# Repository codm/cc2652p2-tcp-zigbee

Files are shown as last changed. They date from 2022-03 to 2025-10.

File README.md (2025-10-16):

# cod.m ZigBee CC2652P2 TCP Coordinator
Initiated by Matthias' video to build a [ZigBee Coordinator with Ethernet connectivity](https://www.youtube.com/watch?v=Uz26JzOJVTc) we developed a small PCB to integrate everything in a small form factor - ready to go if you like.

The coordinator uses an CC2652P2 together with an [USR-K6](https://www.pusr.com/products/low-cost-ttl-to-ethernet-modules-usr-k6.html) serial ethernet gateway. The CC2652P2 is the current ZigBee implementation from Texas Intruments and supports ZigBee 3.x. The Z-Stack firmware is actively developed - much thanks to @koenkk again.

Should be usable with any Home Automation System that let's you use a TCP port instead of a local port. The module is tested with [io.broker](https://www.iobroker.net/) and [zigbee2mqtt](https://www.zigbee2mqtt.io/).

You can buy it at our webshop: https://shop.codm.de/automation/zigbee/40/zigbee-cc2652p2-tcp-ethernet-coordinator. It comes preconfigured with DHCP enabled, case and antenna.

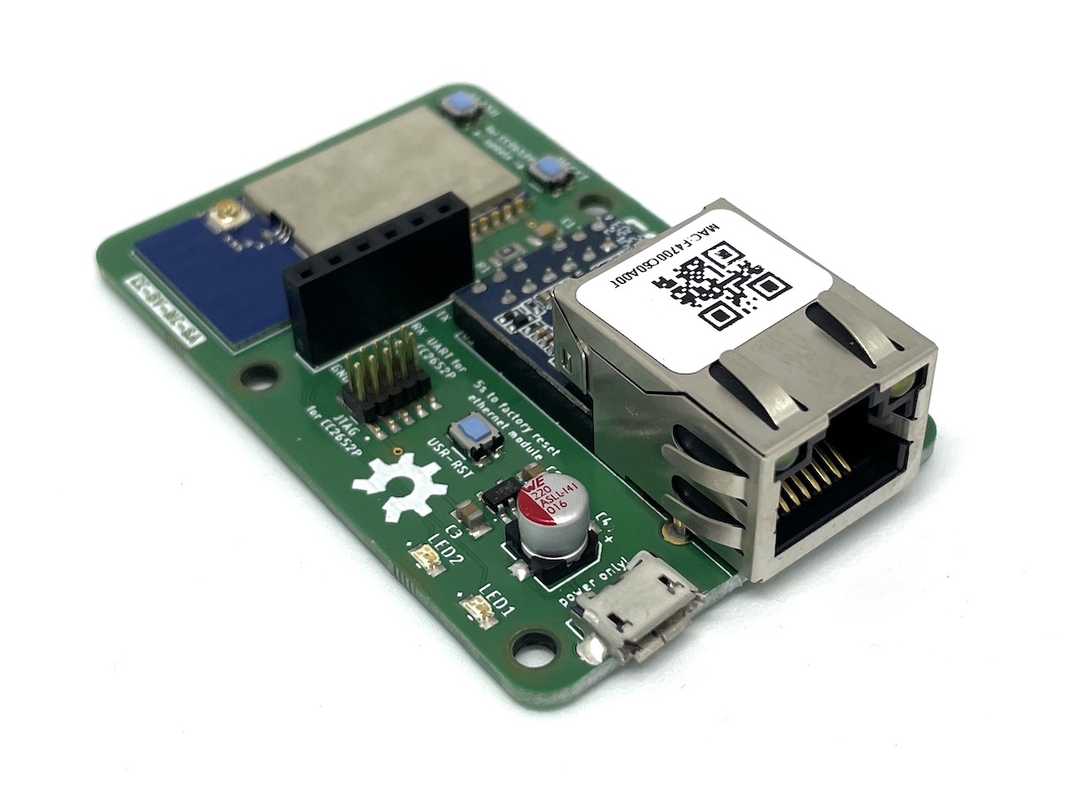
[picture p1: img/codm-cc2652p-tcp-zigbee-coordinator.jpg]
cod.m CC2652P2 TCP ZigBee Coordinator


To build a serial bridge the USR-K6 from USR IOT comes into play which implements everything needed to act as an TCP Server with a webinterface and in a small form factor.

You can find the files to 3d print the case on printables:
https://www.printables.com/de/model/179517-codm-cc2652p2-tcp-zigbee-coordiantor-case

## Configuration
If your home automation system let's you configure `TI ZStack/CCxxxx` devices as ZigBee coordinator over a TCP connection, you should be good to go. 

### io.broker
Install the zigbee adapter and configure the portname to `tcp://<ip-of-cc2652p-tcp>:20108` and choose `TI ZStack/CCxxxx` under type. After restarting the adapter everything should work. Check the logs for details like

```
Coordinator firmware version: {"type":"zStack3x0","meta":{"transportrev":2,"product":1,"majorrel":2,"mino rrel":7,"maintrel":1,"revision":20220103}}
```

### zigbee2mqtt
In `data/configuration.yaml` use the tcp connection under port in the section serial like so (including single quotes): 
```
serial: 
  port: 'tcp://<ip-of-cc2652p-tcp>:20108'
```

### USR-K6
If you factory reset the USR-K6 you'll need to configure the serial bridge again (see image). It act's as a TCP-Server on the given port.

The default IP of the USR-K6 is `192.168.0.7` and username/password for the webinterface is `admin/admin`.

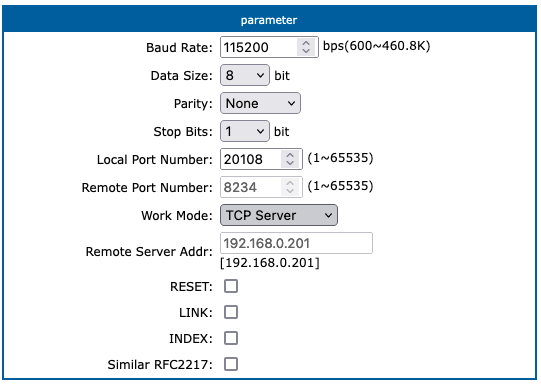
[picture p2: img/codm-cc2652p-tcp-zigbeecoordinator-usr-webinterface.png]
USR-K6 configuration


## Update
You can update the Z-Stack firmware on the CC2652P2 module via network using [ZigStar's stunning ZigStar MultiTool](https://zig-star.com/radio-docs/zigstar-multi-tool/).

Find the Z-Stack Firmware in [Koenkks Z-Stack Firmware Repository]([https://github.com/Koenkk/Z-Stack-firmware/tree/master/coordinator/Z-Stack_3.x.0/bin](https://github.com/Koenkk/Z-Stack-firmware/releases)) and check the table for which file use for the __cod.m ZigBee CC2652P2 TCP Coordinator__. Usually this is `CC1352P2_CC2652P_launchpad_*.zip`.

Open up the case and bring the CC2652P2 in bootloader mode by holding FLASH, pressing RESET and then release FLASH. After that choose the settings in the MultiTool according to the screenshot and of course use the IP of _your_ CC2652P TCP Coordinator:

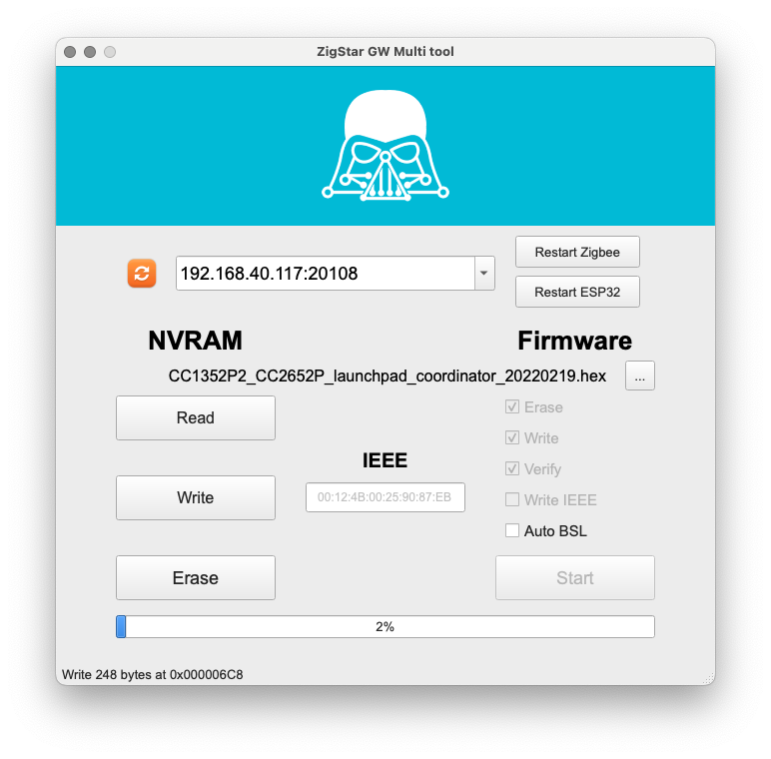
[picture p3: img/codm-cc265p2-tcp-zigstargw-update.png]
ZigStar MultTool Configuration for cod.m CC2652P2 ZigBee Coordinator


After that powercycle the module and use again.

Flashing via JTAG is also possible through the corresponding header.

# Thanks
* @klein0r Inital Idea - https://haus-automatisierung.com/
* @koenkk Z-Stack Firmware - https://github.com/Koenkk/Z-Stack-firmware
* @xyzroe ZigStar MultiTool - https://github.com/xyzroe/ZigStarGW-MT

# License
[CC-BY-NC-SA 4.0](https://creativecommons.org/licenses/by-nc-sa/4.0/)

[][cc-by-nc-sa]

[cc-by-nc-sa]: http://creativecommons.org/licenses/by-nc-sa/4.0/
[cc-by-nc-sa-image]: https://licensebuttons.net/l/by-nc-sa/4.0/88x31.png

cod.m GmbH, Patrik Mayer, 2022

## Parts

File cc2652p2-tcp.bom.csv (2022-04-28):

Qty | Value | Device | Package | Parts | Description | APPLICATION | CHIP-TECHNOLOGY | DATASHEET-URL | DESCRIPTION | DF | DIAMETER | DOMINANT-WAVELENGTH | EMITTING-COLOR | FORWARD-VOLTAGE | GENDER | GERDER | H | HEIGHT | I-LEAK | I-RIPPLE | INTERFACE-TYPE | IR | IR1 | L | LUMINOUS-INTENSITY | MANUFACTURER_NAME | MANUFACTURER_PART_NUMBER | MOUNT | MOUSER_PART_NUMBER | MOUSER_PRICE-STOCK | OPERATING-TEMPERATURE | OPERATION-FORCE | PACKAGING | PART-NUMBER | PEAK-WAVELENGTH | PINS | PITCH | POPULARITY | PROD_ID | QTY | ROWS | SPICEPREFIX | TECHNICAL-REFERENCE | TYPE | VALUE | VR | WORKING-VOLTAGE | Z
3 |  | 434153017835 | 434153017835 | FLASH, RESET, USR-RST | WS-TASV J-Bend SMT Tact Switch 3.5x2.9 mm |  |  | https://www.we-online.com/catalog/datasheet/434153017835.pdf |  |  |  |  |  |  |  |  | 1.7mm |  |  |  |  |  |  |  |  |  |  |  |  |  |  | 350g |  | 434153017835 |  |  |  |  |  | 4000
1 | 61300611821 | 6130XX11821_61300611821 | 61300611821 | J2 | WR-PHD 2.54 mm Socket Header |  |  | https://www.we-online.com/catalog/datasheet/61300611821.pdf |  |  |  |  |  |  | Socket Header |  |  |  |  |  |  | 3A |  |  |  |  |  | THT |  |  |  |  | Tray | 61300611821 |  | 6 | 2.54mm |  |  |  | Single |  |  | Straight | 61300611821
1 | 100n | C-EUC0805 | C0805 | C1 | CAPACITOR, European symbol |  |  |  |  |  |  |  |  |  |  |  |  |  |  |  |  |  |  |  |  |  |  |  |  |  |  |  |  |  |  |  |  | 88 |  |  |  | C
1 | 150080GS75000 | WL-SMCW_0805_150080GS75000 | WL-SMCW_0805 | LED1 | WL-SMCW SMT Mono-color Chip LED Waterclea |  | InGaN | https://www.we-online.com/catalog/datasheet/150080GS75000.pdf |  |  |  | 525nm | Green | 140° |  |  |  |  |  |  |  |  |  |  | 450mcd |  |  |  |  |  |  |  |  | 150080GS75000 | 515nm |  |  |  |  |  |  |  |  |  | 150080GS75000
1 | 150080RS75000 | WL-SMCW_0805_150080RS75000 | WL-SMCW_0805 | LED2 | WL-SMCW SMT Mono-color Chip LED Waterclea |  | AlInGaP | https://www.we-online.com/catalog/datasheet/150080RS75000.pdf |  |  |  | 625nm | Red | 140° |  |  |  |  |  |  |  |  |  |  | 150mcd |  |  |  |  |  |  |  |  | 150080RS75000 | 630nm |  |  |  |  |  |  |  |  |  | 150080RS75000
1 | 1k | R-EU_R0805 | R0805 | R1 | RESISTOR, European symbol |  |  |  |  |  |  |  |  |  |  |  |  |  |  |  |  |  |  |  |  |  |  |  |  |  |  |  |  |  |  |  |  | 86 |  |  |  | R
2 | 1u | C-EUC0805 | C0805 | C2, C3 | CAPACITOR, European symbol |  |  |  |  |  |  |  |  |  |  |  |  |  |  |  |  |  |  |  |  |  |  |  |  |  |  |  |  |  |  |  |  | 88 |  |  |  | C
1 | 20021121-00010C4LF | 20021121-00010C4LF | 2002112100010C4LF | JTAG | Headers & Wire Housings 1.27x1.27mm BTB, Hdr Unshrd, SMT, 10 Pos |  |  |  | Headers & Wire Housings 1.27x1.27mm BTB, Hdr Unshrd, SMT, 10 Pos |  |  |  |  |  |  |  |  | 4.55mm |  |  |  |  |  |  |  | Amphenol | 20021121-00010C4LF |  | 649-202112100010C4LF | https://www.mouser.com/Search/Refine.aspx?Keyword=649-202112100010C4LF
1 | 22 µF | WCAP-ASLL_5X5.5_865060342002 | WCAP-ASLL_5X5.5(DXL) | C4 | WCAP-ASLL Aluminium Electrolytic Capacitors |  |  | https://www.we-online.com/catalog/datasheet/865060342002.pdf |  | 16% | 5mm |  |  |  |  |  |  |  | 3.52uA | 150mA |  |  |  | 5.5mm |  |  |  |  |  |  | -55 °C up to +105 °C |  |  | 865060342002 |  |  |  |  |  |  |  |  | ASEC055220M016DVCTBB000 |  | 22 µF | 16V(DC) |  | 0.8Ohm
2 | 2k7 | R-EU_R0805 | R0805 | R2, R3 | RESISTOR, European symbol |  |  |  |  |  |  |  |  |  |  |  |  |  |  |  |  |  |  |  |  |  |  |  |  |  |  |  |  |  |  |  |  | 86 |  |  |  | R
1 | 629105150921 | 629105150921 | 629105150921 | J1 | WR-COM Micro USB 2.0 Type AB Horizontal | Micro USB 2.0 |  | https://www.we-online.com/catalog/datasheet/629105150921.pdf |  |  |  |  |  |  |  | Receptacle |  |  |  |  | Type AB |  | 1.8A |  |  |  |  | SMT |  |  |  |  | Tape and Reel | 629105150921 |  | 5 |  |  |  |  |  |  |  | Horizontal | 629105150921 |  | 30V(AC)
1 | AP2112K | V_REG_AP2112K-3.3V | SOT23-5 | U2 | AP2112 - 600mA CMOS LDO Regulator w/ Enable |  |  |  |  |  |  |  |  |  |  |  |  |  |  |  |  |  |  |  |  |  |  |  |  |  |  |  |  |  |  |  |  |  | VREG-12457 |  |  |  |  |  | 3.3V
1 | CC2652P2-DUOWEISI | CC2652P2-DUOWEISI | CC2652P2-DUOWEISI | U1
1 | USR-K6 | USR-K6 | USR-K6 | U3

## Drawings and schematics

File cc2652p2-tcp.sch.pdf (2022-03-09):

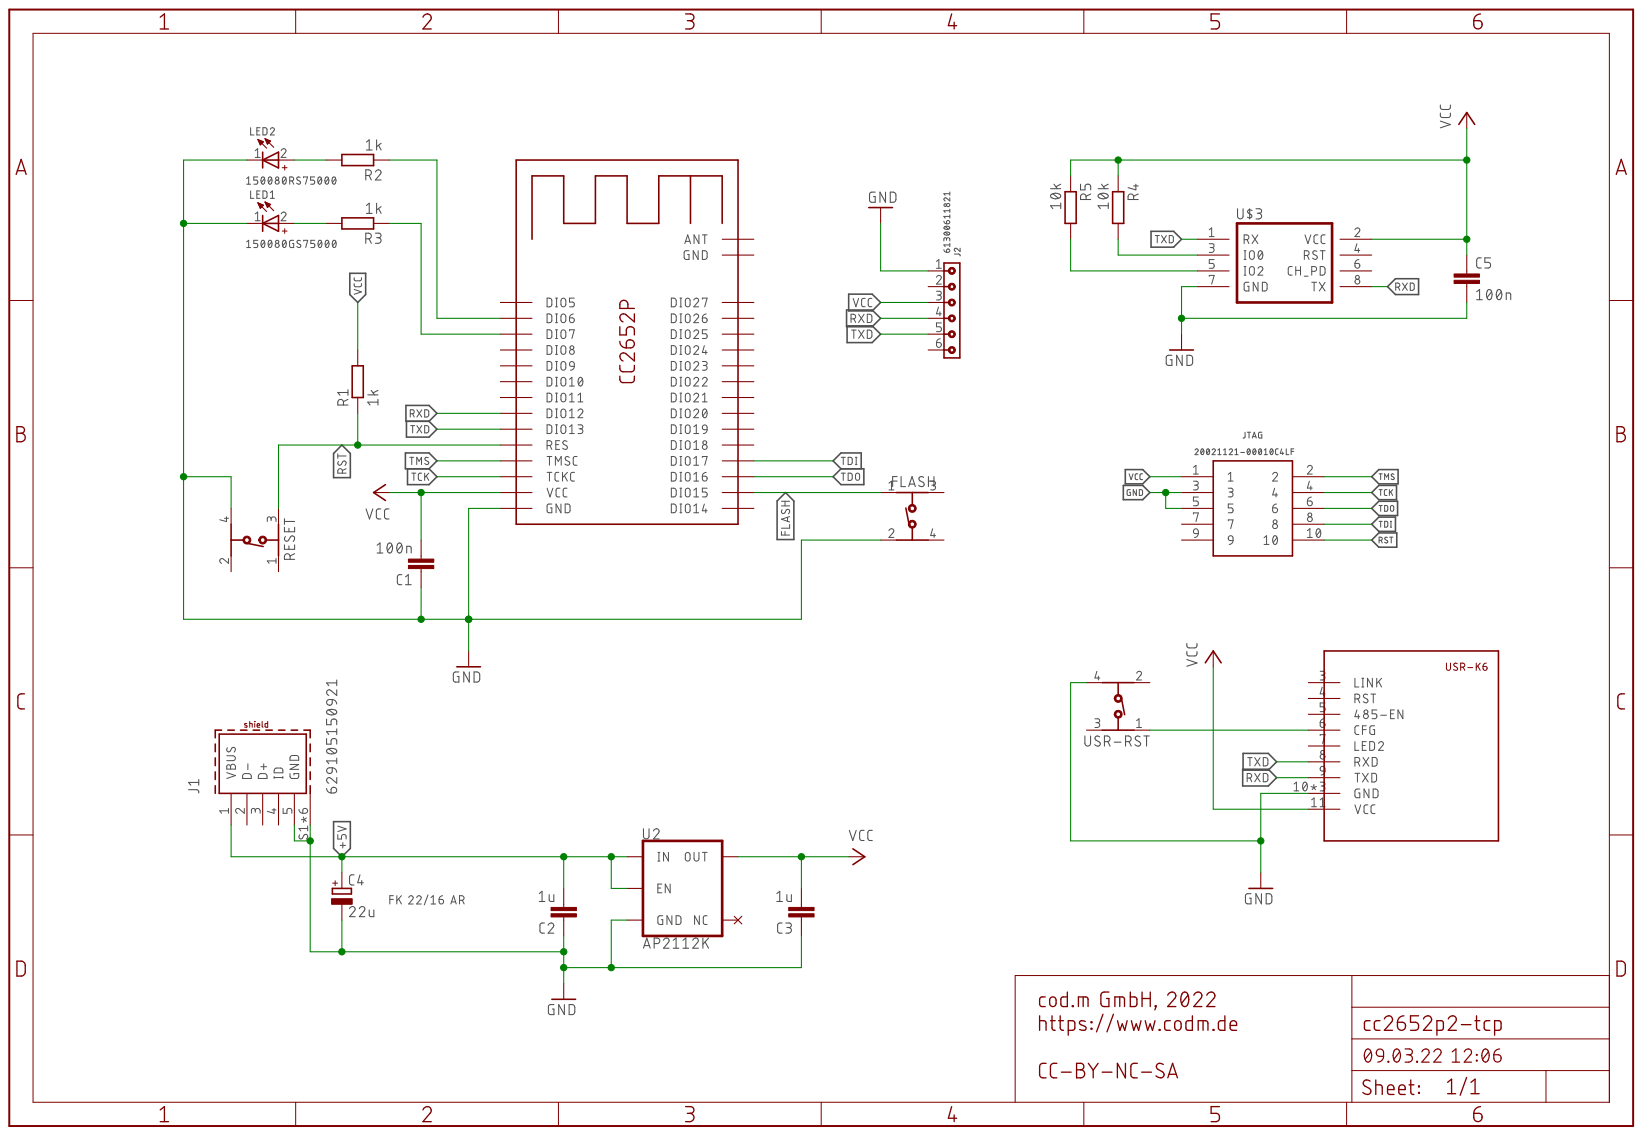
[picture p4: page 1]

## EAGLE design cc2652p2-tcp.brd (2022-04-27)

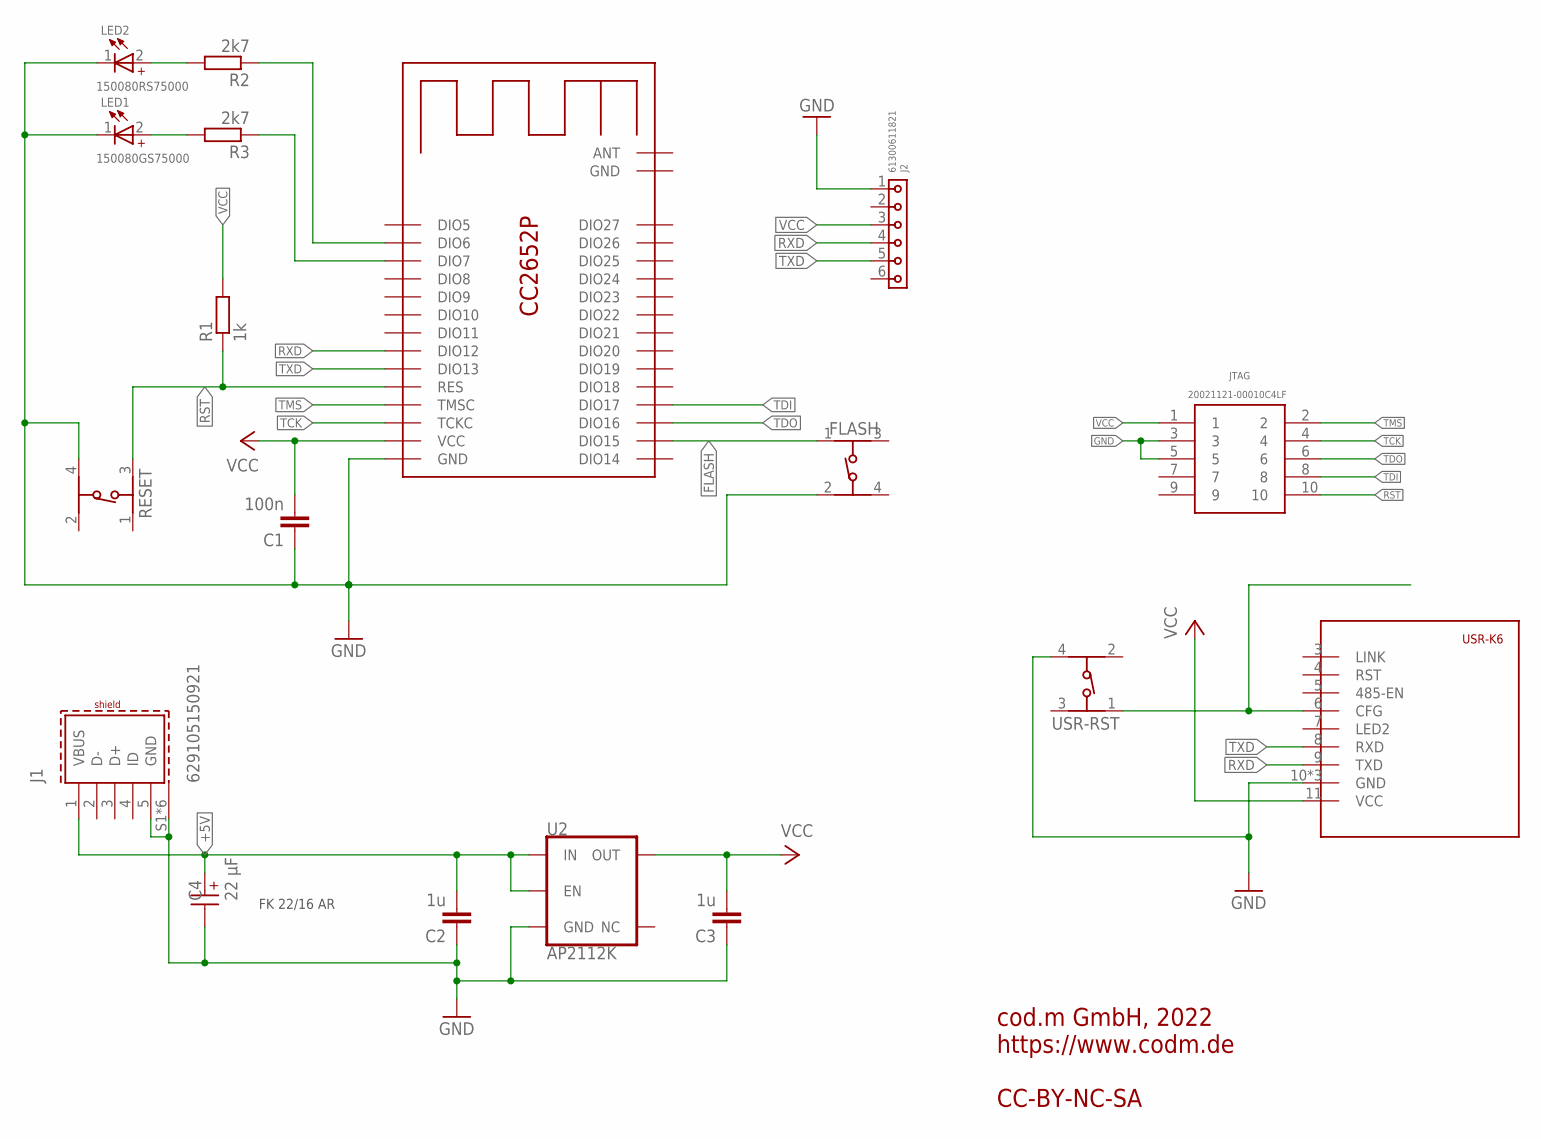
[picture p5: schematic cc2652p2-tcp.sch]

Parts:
C1: 100n; C0805
C2, C3: 1u; C0805
C4: 22 µF; WCAP-ASLL_5X5.5(DXL)
FLASH: 434153017835
J1: 629105150921
J2: 61300611821
JTAG: 20021121-00010C4LF; 2002112100010C4LF
LED1: 150080GS75000; WL-SMCW_0805
LED2: 150080RS75000; WL-SMCW_0805
R1: 1k; R0805
R2, R3: 2k7; R0805
RESET: 434153017835
U1: CC2652P2-DUOWEISI
U2: AP2112K; SOT23-5
U3: USR-K6
USR-RST: 434153017835

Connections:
+5V: C2.2, C4.1 (+), J1.1 (VBUS), U2.1 (IN), U2.3 (EN)
FLASH: FLASH.1, U1.DIO15
GND: C1.1, C2.1, C3.1, C4.2 (-), FLASH.2 (3), J1.5 (GND), J1.S1 (SHIELD), J1.S2 (SHIELD), J1.S3 (SHIELD), J1.S4 (SHIELD), J1.S5 (SHIELD), J1.S6 (SHIELD), J2.1, JTAG.3, JTAG.5, LED1.1 (-), LED2.1 (-), RESET.4, U1.GND, U2.2 (GND), U3.10 (GND), U3.GND@1 (GND), U3.GND@2 (GND), USR-RST.4
unnamed: U3.6 (CFG), USR-RST.1
unnamed: R3.1, U1.DIO7
unnamed: R2.1, U1.DIO6
unnamed: LED2.2 (+), R2.2
unnamed: LED1.2 (+), R3.2
RST: JTAG.10, R1.1, RESET.3 (2), U1.RES
RXD: J2.4, U1.DIO12, U3.9 (TXD)
TCK: JTAG.4, U1.TCKC
TDI: JTAG.8, U1.DIO17
TDO: JTAG.6, U1.DIO16
TMS: JTAG.2, U1.TMSC
TXD: J2.5, U1.DIO13, U3.8 (RXD)
VCC: C1.2, C3.2, J2.3, JTAG.1, R1.2, U1.VCC, U2.5 (OUT), U3.11 (VCC)

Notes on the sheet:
cod.m GmbH, 2022 https://www.codm.de CC-BY-NC-SA
FK 22/16 AR

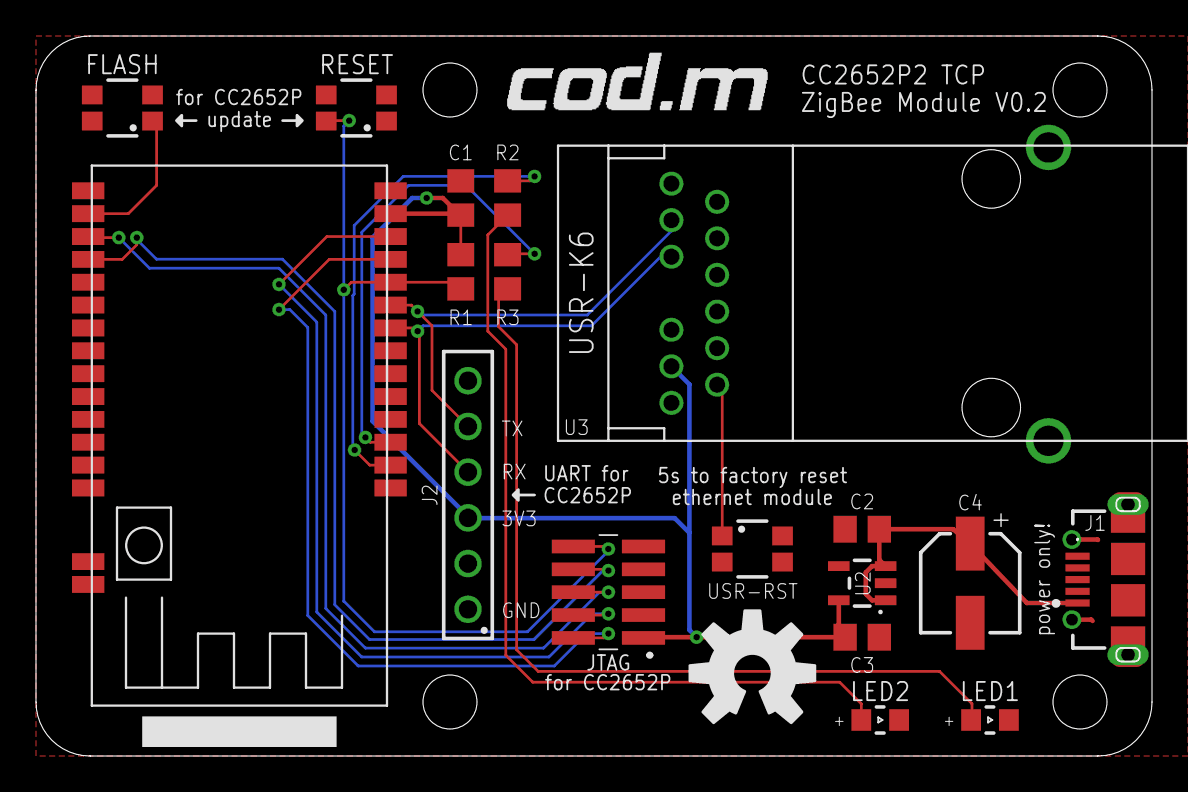
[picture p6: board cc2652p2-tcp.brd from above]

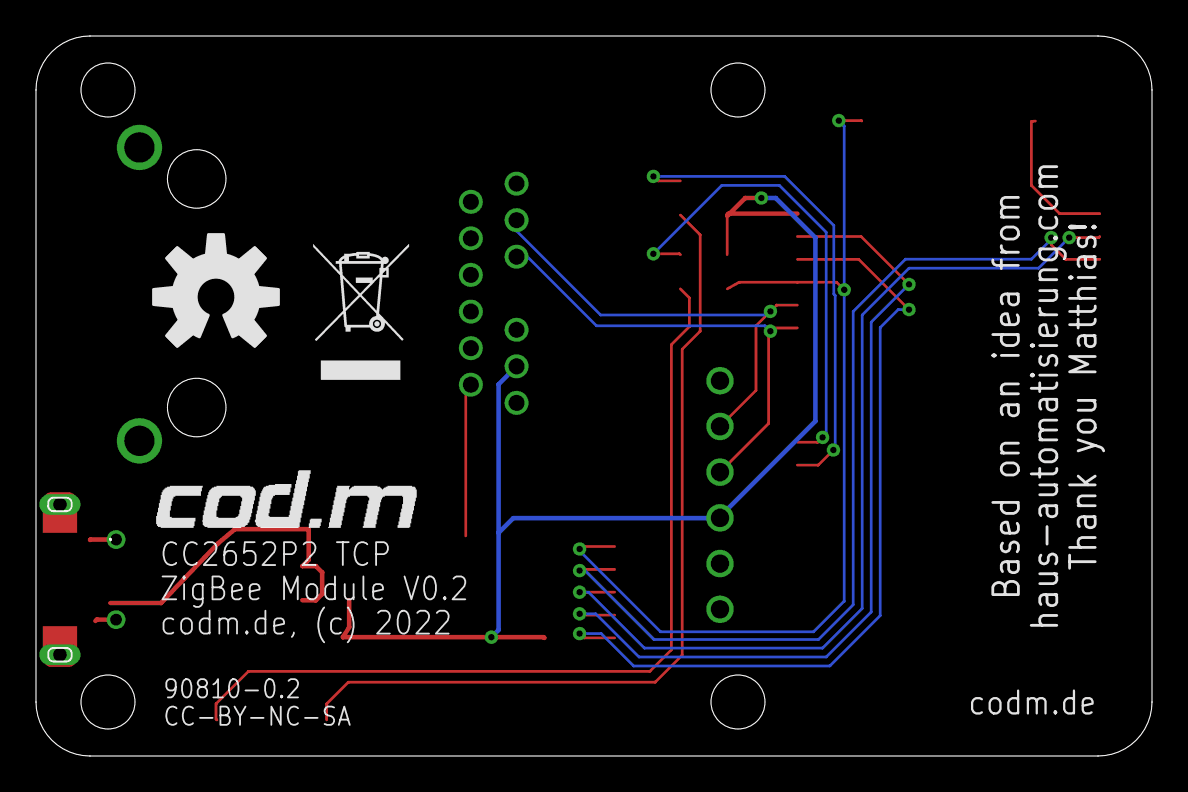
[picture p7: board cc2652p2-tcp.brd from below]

Board: 2 copper layers, 62.0 x 40.0 mm, 23 parts (3 on the bottom side), 16 nets.

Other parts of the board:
U$1, U$2: CODM-LOGO
U$4, U$5: OSHW-LOGO-L
U$6: WEEE-LOGO-5MM

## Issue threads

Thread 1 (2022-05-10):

[REQUEST] Zeroconf support to cod.m ZigBee CC2652P2 TCP Coordinator for Home Assistant ZHA network discovery

Hedda, 2022-05-10:
Please consider adding Zeroconf support to cod.m ZigBee CC2652P2 TCP Coordinator firmware for automatic ZHA network discovery.

Home Assistant OS (formerly HASSIO) supports automatic network scanning and “Service Discovery” via Zeroconf and when a whitelisted Zigbee serial gateway is discovered it can pass along that to a domain like the ZHA integration component in Home Assistant.

For more details see:

https://community.home-assistant.io/t/zha-automatic-discovery-of-zigbee-coordinator-bridges-gateways-ethernet-wifi-network-devices-that-support-zeroconf-or-ssdp/2933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

As a proof-of-concept this is now supported by Tube's Zigbee gateways (based on ESPHome firmware):

https://www.home-assistant.io/integrations/zha#discovery-via-usb-or-zeroconf

https://github.com/tube0013/tube_gateways

Once support for Zeroconf has been added to the firmware you also need the firmware to provide DNS TXT records for passing along setting parameters to integration config flows.

DNS TXT records could be used to pass along recommended settings parameters config flow to Home Assistant's ZHA integration:

radio_type=znp
baud_rate=value
data_flow_control=software
tcp_port_serial_gateway=value
Zeroconf DNS TXT records could also be used to pass along hostname, versions, location, MAC address, and more, etc..

http://www.zeroconf.org/Rendezvous/txtrecords.html

https://en.wikipedia.org/wiki/Zero-configuration_networking#DNS-based_service_discovery

https://en.wikipedia.org/wiki/TXT_record

More information about idea of using DNS TXT records for passing along setting parameters in https://github.com/thegroove/esphome-zbbridge#1 and https://github.com/thegroove/esphome-zha-ezsp-zeroconf

PS: By the way, Home Assistant founders/leads now explicitly said this year they will prioritize focus on features like these types:

https://www.home-assistant.io/blog/2022/01/19/streamlining-experiences/

Check out this video at around 11 min 55 sec in where talk about that focus point about making it easier to get started, etc.

https://www.youtube.com/watch?v=t_2D_KoFIfU&t=710s

Hopefully, it should be a greater chance of getting more help from other Home Assistant developers with this if ask them.

Hedda, 2022-05-10:
FYI, PR for ZiGate's Zeroconf has been merged in Home Assistant core making it an example for adding additional more readable:

https://github.com/home-assistant/core/pull/68577

https://github.com/home-assistant/core/blob/dev/homeassistant/components/zha/manifest.json#L85-L88

https://github.com/home-assistant/core/blob/dev/homeassistant/components/zha/config_flow.py#L198-L201

https://github.com/home-assistant/core/blob/dev/tests/components/zha/test_config_flow.py#L80-L107

https://github.com/home-assistant/core/blob/dev/homeassistant/generated/zeroconf.py#L384-L389

codmpm, 2022-05-11:
Hey @Hedda, thanks for the headsup.

I totally would like to do that, but sadly the firmware of the used ethernet serial module (USR-K6) is closed source and currently has no option to set this in the config.
Writing my reseller right now and ask if they can forward this to pusr, the maker of the usr-modules.

Best,
Patrik

Hedda, 2022-05-11:
Doh! Maybe you should consider switching to design with either ESP32 or the Raspberry Pi RP2040 (with Ethernet)? See examples:

https://github.com/tube0013/tube_gateways

https://github.com/mercenaruss/zigstar_gateways/

https://github.com/syssi/esphome-zb-gw03

As you can see there already are a few Zigbee bridges with Ethernet-based on ESP32 but not yet seen any based on RP2040. Ref:

https://www.soselectronic.com/products/wiznet/w5100s-evb-pico-359020

https://www.elektor.com/raspberry-pi/rp2040/wiznet-ethernet-hat-for-raspberry-pi-pico

RP2040 would make it interesting as something new not seen yet, however benefit with ESP32 is Tasmota and ESPHome support:

https://tasmota.github.io/docs/Zigbee/

codmpm, 2022-05-11:
Working on an ESP32 variant, but only internally at this will be the same as tubes gateway. So I see no need.
The plus of the USR variant was, that it could be cheaper while reatining high quality (no ali esp32 ethernet boards).

I know these boards and had prototypes running with tasmota and espeasy. Esphome was on the list but I did not try it as we then used the usr modules.
Let me wait what my reseller says... maybe pusr will update the firmware in any way.

I realy would like to use the RP2040 for this but did not see any software. Already built something with it and am totally excited for the architecture: https://github.com/pa-pa/AskSinPP/discussions/294#discussioncomment-2470725
The WizNet W5500 is at least available. We are checking what we can do.

Hedda, 2022-05-11:
> Working on an ESP32 variant, but only internally at this will be the same as tubes gateway. So I see no need.

I think there probably is a demand and a need for another ESP32 based gateway if shipping from within the European Union.

Tube's gateway are great from an end-user perspective but they have the downside of being out of stock or low stock and belibe being shipped from Australia or the United States(?) which as I'm sure you know gets very costly for customers living in the European Union after both high shipping costs and taxes are added on top of both the actual product and shipping cost.

ZigStar Gateways shipping location from Moldova is a little closer but stil not shipping from within the European Union.

Other than that I think that support for mDNS Zeroconf out-of-the-box and automatic discovery adds value to new users of HA.

PS: Both Tube and ZigStar now also offer PoE (Power-over-Ethernet) models which are more niche but there is also a market for.

codmpm, 2022-05-11:
Yeah, thought about the shipping argument... had the same experience with our WLED controller.

POE for cheap is currently not possible. The best way would be  to use the [Olimex PES32-POE as tubes does](https://www.tubeszb.com/product/cc2652_poe_coordinator/47?cp=true&sa=false&sbp=false&q=false&category_id=2).

Checking out the rp2040 variant though and have something in mind for the ESP32 way. Hopefully with POE.

Hedda, 2022-05-11:
Cool, as you said, will probably sell more without PoE, however, if can offer two variants models then catch those customers too.

codmpm, 2022-05-11:
Thinking about that and leave the PoE part on the PCB unpopulated.

Hedda, 2022-05-11:
> Thinking about that and leave the PoE part on the PCB unpopulated.

FYI, that is what Electrorama have done in order to offer multiple variant models of their zoe and zoe-lite + zoe2 and zoe2-lite.

https://electrolama.com/projects/zoe/

https://www.tindie.com/products/electrolama/zoe-lite-zigbee-radio-for-raspberry-pi/

https://www.tindie.com/products/electrolama/zoe-poe-zigbee-radio-rtc-poe-for-raspberry-pi/

https://electrolama.com/projects/zoe2/

So they have the same PCB but sell some with presoldered PoE module as "zoe2" and some without as "zoe2-lite"
https://shop.electrolama.com/collections/raspberry-pi-addons/products/zoe2-cc1352p-radio-for-raspberry-pi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

https://shop.electrolama.com/collections/raspberry-pi-addons/products/zoe2-cc1352p-radio-rtc-poe-for-raspberry-pi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

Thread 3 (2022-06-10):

[REQUEST] OpenThread Border Router (OTBR) RCP and NCP firmware images for CC2652R based cod.m ZigBee CC2652P2 TCP Coordinator?

Hedda, 2022-06-10:
@codmpm Can you please consider providing OpenThread Border Router (OTBR)  "RCP mode" firmware images well as "NCP mode" firmware images (with support for the OpenThread `spinel+hdlc+uart` protocol) and preferably using the latest SDK for this Texas Instruments CC2652 based adapter so that it will be compatible with the "OpenThread Border Router Add-on" that Home Assistant developer agners (Nabu Casa employee Stefan Agner) is currently developing? Check out:

https://github.com/home-assistant/addons-development/tree/master/openthread_border_router

https://github.com/openthread/ot-br-posix/

https://github.com/agners

https://community.home-assistant.io/u/agners/summary

https://groups.google.com/g/openthread-users/

 OTBR should be a "Thread Certified Component" Texas Instruments CC2652 based chips:

https://github.com/openthread/ot-cc13x2-cc26x2/blob/main/src/cc2652/README.md

https://github.com/openthread/ot-cc13x2-cc26x2

https://github.com/openthread/openthread/tree/main/examples/platforms

https://dev.ti.com/tirex/explore/node?node=APzU0zOtgnQIe0sFnHCfxg__BSEc4rl__LATEST

https://openthread.io/vendors/texas-instruments

https://www.threadgroup.org/What-is-Thread/Thread-Benefits#certifiedproducts

https://training.ti.com/thread-cc2652-cc1352

The main reason for this request is that an "RPC" firmware with OTBR (OpenThread Border Router) support will make your adapter will be compatible with upcoming Thread based "Matter" (Project CHIP / Connected Home over IP) devices if used in Home Assistant with their other add-ons for the that is also in development. This addon by agners requires that the radio hard a firmware in "RPC" mode instead of the no traditional "NCP" mode:

https://github.com/home-assistant/addons-development/tree/master/chip_controller_repl

https://github.com/home-assistant/addons-development/tree/master/chip_tool

https://github.com/project-chip/connectedhomeip

https://buildwithmatter.com

https://csa-iot.org/all-solutions/matter/

Also having optional OpenThread "NCP" border router firmware would allow users to alternatively use other existing OpenThread applications that use "NCP" mode instead of the newer "RPC" mode which require additional component running on the host. Ex:

https://github.com/openthread/wpantund

Note that so far agners has only worked with Silicon Labs based adapter with OpenThread "RPC" firmware for Thread based Matter (as well as ESP32-C3 based devkit for Matter over WiFi) and that is only because it is a Silabs EFR32MG21 chip based adapter that will ship inside the official Home Assistant Yellow (formerly Home Assistant Amber) hardware:

https://github.com/zigpy/zigpy/discussions/894

https://github.com/home-assistant/addons-development/tree/master/silabs-multiprotocol

https://www.home-assistant.io/blog/2021/09/13/home-assistant-yellow/

https://www.crowdsupply.com/nabu-casa/home-assistant-yellow

PS: By the way, you might be interested in the the "Matter" workshop that Home Assistant is holding on the 15th of June even if they are in that specific workshop will not use a Thread based controller or devices and instead use a WiFi (+ Bluetooth) based "Matter" devices:

https://www.home-assistant.io/blog/2022/05/29/matter-in-home-assistant-workshop-announcement/

https://www.youtube.com/watch?v=9fOHBl5w0_k

https://community.home-assistant.io/t/matter-in-home-assistant-workshop-announcement/426129/

codmpm, 2022-06-13:
Dear @Hedda,

as already statwed here (https://github.com/codm/cc2652-raspberry-pi-module/issues/6) we simply use Koenkk's Z-Stack coordinator firmware.
Also the producer of the used ethernet UART boards is not open to modify his firmware.

I'm partly working on an open solution based on an rp2040, already talked about here https://github.com/codm/cc2652p2-tcp-zigbee/issues/1, but I currently have to big time constraints to drive this idea further.

Cheers,
Patrik

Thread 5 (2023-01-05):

Error: Failed to connect to the adapter (Error: SRSP - SYS - ping after 6000ms)

ericvb, 2023-01-05:
Just purchased a brand new cod.m CC2652P2 TCP Zigbee Coordinator V0.2
Trying now to get it working with the HA Zigbee2MQTT addon.
```
data_path: /config/zigbee2mqtt
socat:
  enabled: false
  master: pty,raw,echo=0,link=/tmp/ttyZ2M,mode=777
  slave: tcp-listen:8485,keepalive,nodelay,reuseaddr,keepidle=1,keepintvl=1,keepcnt=5
  options: "-d -d"
  log: false
mqtt:
  server: mqtt://mymqttbroker_IP_address:8883
  user: "!secret mqtt_username"
  password: "!secret mqtt_password"
serial:
  port: tcp://192.168.50.39:20108
advanced:
  log_level: debug
zigbee_herdsman_debug: true
```

This is the log output:
```
[11:28:35] INFO: Preparing to start...
[11:28:35] INFO: Socat not enabled
[11:28:35] INFO: Zigbee Herdsman debug logging enabled
[11:28:35] INFO: Starting Zigbee2MQTT...
Zigbee2MQTT:debug 2023-01-05 11:28:36: Can't load state from file /config/zigbee2mqtt/state.json (doesn't exist)
Zigbee2MQTT:info  2023-01-05 11:28:36: Logging to console and directory: '/config/zigbee2mqtt/log/2023-01-05.11-28-36' filename: log.txt
Zigbee2MQTT:debug 2023-01-05 11:28:36: Removing old log directory '/config/zigbee2mqtt/log/2023-01-04.22-39-48'
Zigbee2MQTT:info  2023-01-05 11:28:36: Starting Zigbee2MQTT version 1.29.0 (commit #unknown)
Zigbee2MQTT:info  2023-01-05 11:28:36: Starting zigbee-herdsman (0.14.83)
Zigbee2MQTT:debug 2023-01-05 11:28:36: Using zigbee-herdsman with settings: '{"adapter":{"concurrent":null,"delay":null,"disableLED":false},"backupPath":"/config/zigbee2mqtt/coordinator_backup.json","databaseBackupPath":"/config/zigbee2mqtt/database.db.backup","databasePath":"/config/zigbee2mqtt/database.db","network":{"channelList":[11],"extendedPanID":[221,221,221,221,221,221,221,221],"networkKey":"HIDDEN","panID":6754},"serialPort":{"path":"tcp://192.168.50.39:20108"}}'
2023-01-05T10:28:37.009Z zigbee-herdsman:adapter Failed to validate path: 'Error: spawn udevadm ENOENT'
2023-01-05T10:28:37.009Z zigbee-herdsman:controller:log Starting with options '{"network":{"networkKeyDistribute":false,"networkKey":[1,3,5,7,9,11,13,15,0,2,4,6,8,10,12,13],"panID":6754,"extendedPanID":[221,221,221,221,221,221,221,221],"channelList":[11]},"serialPort":{"path":"tcp://192.168.50.39:20108"},"databasePath":"/config/zigbee2mqtt/database.db","databaseBackupPath":"/config/zigbee2mqtt/database.db.backup","backupPath":"/config/zigbee2mqtt/coordinator_backup.json","adapter":{"disableLED":false,"concurrent":null,"delay":null}}'
2023-01-05T10:28:37.010Z zigbee-herdsman:adapter:zStack:znp:log Opening TCP socket with 192.168.50.39:20108
2023-01-05T10:28:37.015Z zigbee-herdsman:adapter:zStack:znp:log Socket connected
2023-01-05T10:28:37.015Z zigbee-herdsman:adapter:zStack:znp:log Socket ready
2023-01-05T10:28:37.015Z zigbee-herdsman:adapter:zStack:znp:log Writing CC2530/CC2531 skip bootloader payload
2023-01-05T10:28:37.015Z zigbee-herdsman:adapter:zStack:unpi:writer --> buffer [239]
2023-01-05T10:28:38.018Z zigbee-herdsman:adapter:zStack:znp:log Skip bootloader for CC2652/CC1352
2023-01-05T10:28:38.018Z zigbee-herdsman:adapter:zStack:znp:SREQ --> SYS - ping - {"capabilities":1}
2023-01-05T10:28:38.019Z zigbee-herdsman:adapter:zStack:unpi:writer --> frame [254,0,33,1,32]
2023-01-05T10:28:44.020Z zigbee-herdsman:adapter:zStack:znp:SREQ --> SYS - ping - {"capabilities":1}
2023-01-05T10:28:44.020Z zigbee-herdsman:adapter:zStack:unpi:writer --> frame [254,0,33,1,32]
2023-01-05T10:28:50.026Z zigbee-herdsman:adapter:zStack:znp:SREQ --> SYS - ping - {"capabilities":1}
2023-01-05T10:28:50.026Z zigbee-herdsman:adapter:zStack:unpi:writer --> frame [254,0,33,1,32]
Zigbee2MQTT:error 2023-01-05 11:28:56: Error while starting zigbee-herdsman
Zigbee2MQTT:error 2023-01-05 11:28:56: Failed to start zigbee
Zigbee2MQTT:error 2023-01-05 11:28:56: Check https://www.zigbee2mqtt.io/guide/installation/20_zigbee2mqtt-fails-to-start.html for possible solutions
Zigbee2MQTT:error 2023-01-05 11:28:56: Exiting...
Zigbee2MQTT:error 2023-01-05 11:28:56: Error: Failed to connect to the adapter (Error: SRSP - SYS - ping after 6000ms)
    at ZStackAdapter.start (/app/node_modules/zigbee-herdsman/src/adapter/z-stack/adapter/zStackAdapter.ts:103:27)
    at Controller.start (/app/node_modules/zigbee-herdsman/src/controller/controller.ts:132:29)
    at Zigbee.start (/app/lib/zigbee.ts:58:27)
    at Controller.start (/app/lib/controller.ts:101:27)
    at start (/app/index.js:107:5)
```

Apparently, it can connect to the tcp socket, but then it fails.
Any idea how to debug this? Where to search?

codmpm, 2023-01-05:
Hey there.

are you on the smae network (`192.168.50.0`) as the coordinator?

Personally never hat anything to do with the socat options.
Maybe remove these. Here's a working config from a standalone z2m install.

```
homeassistant: false
permit_join: true
mqtt:
  base_topic: zigbee2mqtt
  server: mqtt://localhost
frontend:
  port: 8080
  host: 0.0.0.0
serial:
  port: tcp://192.168.40.122:20108
devices:
  '0x60a423fffe88148b':
    friendly_name: '0x60a423fffe88148
```

ericvb, 2023-01-05:
I'm running the Home Assistant OS version in a VM box. The VM box is running in another network 192.168.1.x.
A firewall rule is permitting to access the network 192.168.50.0/24
The rule is permitting all services.

The socat options where automatically added to the configuration by the HA Zigbee2MQTT addon.
I will test without the socat options.

ericvb, 2023-01-05:
I will try to set the adapter directly into the 192.168.1.x network, to exclude firewall rules problems.
If no result, add an issue in the Koenkk github repo?

ericvb, 2023-01-06:
No luck in trying to use the adapter in the same 192.168.1.x network. Same log result.

@codmpm, is there a way to test the hardware without using HA?

ericvb, 2023-01-06:
I've tested with the latest docker image of zigbee2mqtt using the same configuration
```
# Home Assistant integration (MQTT discovery)
homeassistant: false

# allow new devices to join
permit_join: true

# MQTT settings
mqtt:
  # MQTT base topic for zigbee2mqtt MQTT messages
  base_topic: zigbee2mqtt
  # MQTT server URL
  server: 'mqtt://myipmqttserver:8883'
  # MQTT server authentication, uncomment if required:
  user: xxx
  password: xxx

# Serial settings
serial:
  # Location of CC2531 USB sniffer
  port: tcp://192.168.50.39:20108

advanced:
  log_level: debug
```

```
eric@aeolus:~/zigbee2mqtt/data$ sudo docker run \
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
Using '/app/data' as data directory
Zigbee2MQTT:debug 2023-01-06 12:48:53: Can't load state from file /app/data/state.json (doesn't exist)
Zigbee2MQTT:info  2023-01-06 12:48:53: Logging to console and directory: '/app/data/log/2023-01-06.12-48-53' filename: log.txt
Zigbee2MQTT:info  2023-01-06 12:48:53: Starting Zigbee2MQTT version 1.29.1 (commit #7d67ffc)
Zigbee2MQTT:info  2023-01-06 12:48:53: Starting zigbee-herdsman (0.14.83)
Zigbee2MQTT:debug 2023-01-06 12:48:53: Using zigbee-herdsman with settings: '{"adapter":{"concurrent":null,"delay":null,"disableLED":false},"backupPath":"/app/data/coordinator_backup.json","databaseBackupPath":"/app/data/database.db.backup","databasePath":"/app/data/database.db","network":{"channelList":[11],"extendedPanID":[221,221,221,221,221,221,221,221],"networkKey":"HIDDEN","panID":6754},"serialPort":{"path":"tcp://192.168.50.39:20108"}}'
2023-01-06T11:48:53.781Z zigbee-herdsman:controller:log Starting with options '{"network":{"networkKeyDistribute":false,"networkKey":[1,3,5,7,9,11,13,15,0,2,4,6,8,10,12,13],"panID":6754,"extendedPanID":[221,221,221,221,221,221,221,221],"channelList":[11]},"serialPort":{"path":"tcp://192.168.50.39:20108"},"databasePath":"/app/data/database.db","databaseBackupPath":"/app/data/database.db.backup","backupPath":"/app/data/coordinator_backup.json","adapter":{"disableLED":false,"concurrent":null,"delay":null}}'
2023-01-06T11:48:53.783Z zigbee-herdsman:adapter:zStack:znp:log Opening TCP socket with 192.168.50.39:20108
2023-01-06T11:48:53.789Z zigbee-herdsman:adapter:zStack:znp:log Socket connected
2023-01-06T11:48:53.789Z zigbee-herdsman:adapter:zStack:znp:log Socket ready
2023-01-06T11:48:53.790Z zigbee-herdsman:adapter:zStack:znp:log Writing CC2530/CC2531 skip bootloader payload
2023-01-06T11:48:53.790Z zigbee-herdsman:adapter:zStack:unpi:writer --> buffer [239]
2023-01-06T11:48:54.793Z zigbee-herdsman:adapter:zStack:znp:log Skip bootloader for CC2652/CC1352
2023-01-06T11:48:54.793Z zigbee-herdsman:adapter:zStack:znp:SREQ --> SYS - ping - {"capabilities":1}
2023-01-06T11:48:54.794Z zigbee-herdsman:adapter:zStack:unpi:writer --> frame [254,0,33,1,32]
2023-01-06T11:49:00.801Z zigbee-herdsman:adapter:zStack:znp:SREQ --> SYS - ping - {"capabilities":1}
2023-01-06T11:49:00.801Z zigbee-herdsman:adapter:zStack:unpi:writer --> frame [254,0,33,1,32]
2023-01-06T11:49:06.808Z zigbee-herdsman:adapter:zStack:znp:SREQ --> SYS - ping - {"capabilities":1}
2023-01-06T11:49:06.808Z zigbee-herdsman:adapter:zStack:unpi:writer --> frame [254,0,33,1,32]
Zigbee2MQTT:error 2023-01-06 12:49:12: Error while starting zigbee-herdsman
Zigbee2MQTT:error 2023-01-06 12:49:12: Failed to start zigbee
Zigbee2MQTT:error 2023-01-06 12:49:12: Check https://www.zigbee2mqtt.io/guide/installation/20_zigbee2mqtt-fails-to-start.html for possible solutions
Zigbee2MQTT:error 2023-01-06 12:49:12: Exiting...
Zigbee2MQTT:error 2023-01-06 12:49:12: Error: Failed to connect to the adapter (Error: SRSP - SYS - ping after 6000ms)
    at ZStackAdapter.start (/app/node_modules/zigbee-herdsman/src/adapter/z-stack/adapter/zStackAdapter.ts:103:27)
    at Controller.start (/app/node_modules/zigbee-herdsman/src/controller/controller.ts:132:29)
    at Zigbee.start (/app/lib/zigbee.ts:58:27)
    at Controller.start (/app/lib/controller.ts:101:27)
    at start (/app/index.js:107:5)

```

I see in the webinterface of the tcp server USR-K6, that I can do a reset. Should I try this?

codmpm, 2023-01-06:
Yes, please try that. See here https://github.com/codm/cc2652p2-tcp-zigbee#usr-k6 how it should ne set up.

ericvb, 2023-01-06:
I did the reset (= clicked the RESET box in the USR-K6 webinterface and saved and restarted the module)
After that no change in behaviour, same error logging.

The hardware CC2652P2 TCP ZigBee Coordinator V0.2 was from the batch from end december 2022.
Did you hear anything about simular problems?

I see that with the ZigStar GW Multitool, I can 'Verify' the firmware. I will try that.

codmpm, 2023-01-06:
No, no such problems reported.

Using the ZigStar GW Multitool you can update the Z-Stack firmware on the CC2652. This is completely independent from the firmware of the LAN module (USRIOT USR-K6).

If nothing helps we will arange repair in any form.

ericvb, 2023-01-06:
I think I know what the problem is.
When I opened the box, I saw this

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

There was apparently a problem in soldering the components...

codmpm, 2023-01-06:
Woah. Ok. That is definetly not ok.
I'll send you a label for sending the coordinator back to us so we can repair it.

Please hit me up on support@codm.de to verify the address.

Sorry for that.

ericvb, 2023-01-06:
No problem, this can happen :-)

I've send you an email.

ericvb, 2023-01-15:
Hi @codmpm,
Thank you for the quick repair of the unit. Everything is working now.
Regards,

Closed 2023-01-15.

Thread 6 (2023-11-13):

What should be normal values of the Link quality between the coordinator cc2652p2-tcp-zigbee and a power adapter seeing each other

ericvb, 2023-11-13:
Never payed attention to it because it did work. But now I have a Sonoff doorsensor who goes offline some hours after his pairing.
After making my homework about Link quality, I should expect that between the Z5 power adapter and the coordinator, I should see above 150 as link quality...

I know that there are hundred of articles about How to make your Zigbee network performant?
But for example I see between the Lightstrip and the Z5, 179/154. There is a brick wall between them.
Between the radiator endpoints and the lightstrip there is a concrete floor and brick wall, very good link quality
Between Z1, Z5 and lightstrip, very good Link quality (brick wall between them)
So, in my opinion, the Zigbee signal is not disturbed by e.g. my wifi signal (I payed attention to configure different channels)
So why these bad link quality values to the coordinator? The coordinator is placed a 0.5m under the ceiling of Floor 0.

See attachment for the network map.
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

codmpm, 2023-11-14:
Hey Eric,

not sure if we can help here as we simply use Koenkk's Z-Stack Firmware on a CC2652P2. As far as I know the linquality is determined by zhe ZigBee-Mesh itself, but I'm no expert on this.
Maybe you can ask this here: https://github.com/Koenkk/Z-Stack-firmware/issues

Cheers,
Patrik

ericvb, 2023-11-14:
Hi Patrick,

But when you have tested your hardware, what where the Link quality values?
My device is 3m away from the coordinator. My device is 0.5m from the floor and the Coordinator is placed 0.5m from the ceiling.
I should expect high link quality values :-(

Following your link to Koenkk, I found following issue : https://github.com/Koenkk/Z-Stack-firmware/discussions/474
But I did receive my coordinator January this year, so I should still have a 2022 firmware version.
Can I see with that ZigStarr multitool the installed firmware version of my coordinator?

Regards,
Eric

ericvb, 2024-01-02:
A follow-up.

I finally didn't update the coordinator due to the problems mentioned in https://github.com/Koenkk/Z-Stack-firmware/discussions/474
I bought an other door sensor, a white Chinese product, a TS0203 based one (_TZ3000_oxslv1c9).
This sensor does not go offline in the existing described configuration (see opening first issue message)

The Sonoff door sensor is now on my desk, in visual sight of view of a router. The sensor does go still offline after some time, but opening the sensor makes him go online again automatically.
So conclusion, the Sonoff sensor is working, his going offline is probably by design, but if too far away from a coordinator or router, the sensor will not come back online if his state is changing.

I'm closing now this ticket. Thanks for your time.

Closed 2024-01-02.

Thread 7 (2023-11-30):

[REQUEST NEWER HARDWARE] CC2674 (CC2674P/CC2674R) and CC1354P (CC1354P) Zigbee Coordinator and Zigbee Router adapters?

Hedda, 2023-11-30:
Will you consider making CC2674/CC2674P/CC2674R and/or CC1354/CC1354P Zigbee adapters for developers and early-adopters?

Check out this developer discussion in Koenkk's Z-Stack firmware repository -> https://github.com/Koenkk/Z-Stack-firmware/discussions/476

There is no community firmware from Koenkk yet but that is probably partially because no one made a CC2674 or CC1354 adapter yet.

Chicken or the egg, what comes first, early prototype adapters that Koenkk can test or firmware built in the blind?

FYI, E72-2G4M20S1C (CC2674P10) radio module from Ebyte/Cdebyte is already available for prototyping and first-to-market devices:

https://www.cdebyte.com/products/E72-2G4M20S1C

According to [LSagiroglu](https://github.com/LSagiroglu) this new CC2674P10 based module is is pin to pin compatible with their CC2652P based module:

https://www.cdebyte.com/products/E72-2G4M20S1E

PS: No news so far from RFstar if they are working on CC2674P or CC1354P radio modules yet.

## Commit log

2022-03-14 tests with ESP-01
    [cc2652p2-tcp.brd, cc2652p2-tcp.sch]
2022-03-14 removed ESP-01
    [cc2652p2-tcp.brd, cc2652p2-tcp.sch]
2022-04-27 removed old csv
    [cc2652p2-tcp.csv]
2022-04-28 correction on bom
    [cc2652p2-tcp.bom.csv, cc2652p2-tcp.bom.xlsx]

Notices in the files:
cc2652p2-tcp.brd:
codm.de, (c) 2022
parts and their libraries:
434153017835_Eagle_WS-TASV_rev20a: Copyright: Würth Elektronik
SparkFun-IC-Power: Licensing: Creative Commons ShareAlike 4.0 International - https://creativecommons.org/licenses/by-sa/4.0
